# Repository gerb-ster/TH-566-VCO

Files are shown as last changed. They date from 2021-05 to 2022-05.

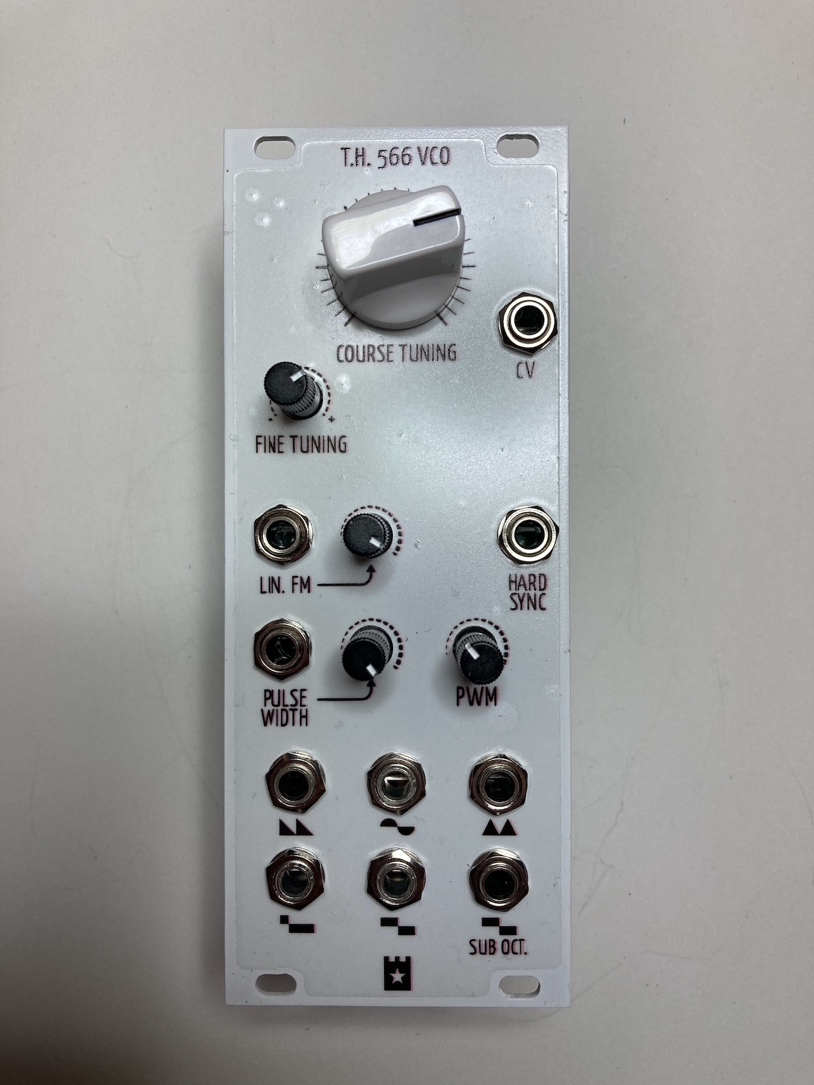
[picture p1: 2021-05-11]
images/IMG_3571.jpeg

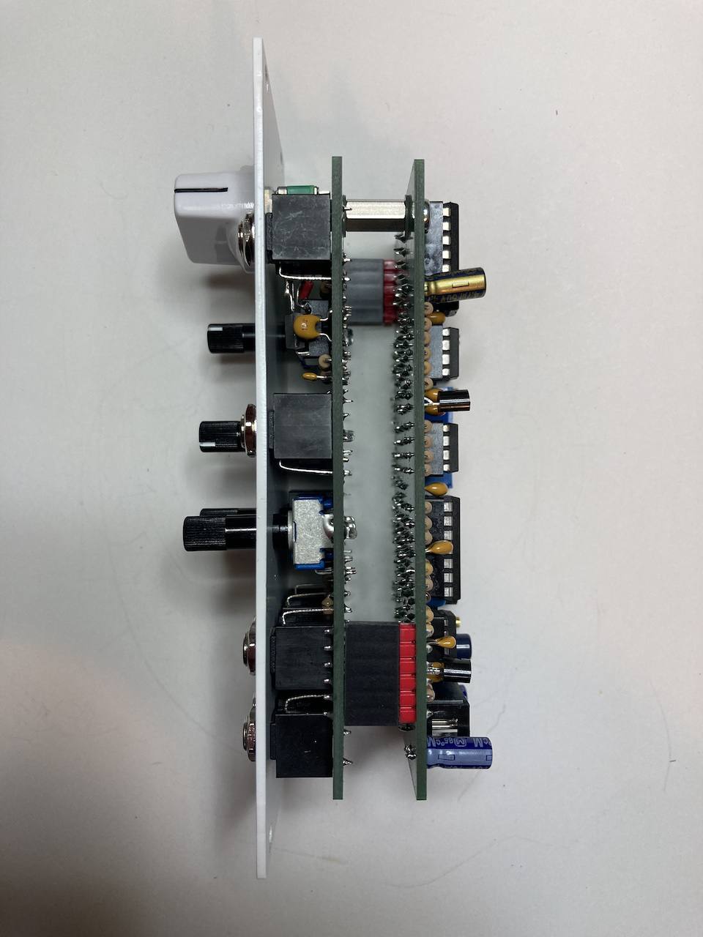
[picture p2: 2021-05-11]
images/IMG_3572.jpeg

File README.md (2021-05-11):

# Thomas Henry 566 VCO

Some years ago I bought a booklet called ‘making music with the 566’ by Thomas Henry. The first time I read it, I understood maybe 10 percent. Since then, every year or so, I’d read it again, and it started making more and more sense. And last year I decided it was time to try and make a PCB for it. So here it is. I’ve added a wave shaper to turn the triangle wave into a saw wave. I made some minor mistakes in the first PCB design, but these are fixed in the schematics below.

## Status: Finished

- done: first schematic & board design
- done: breadboard and test
- done: design frontpanel
- done: order PCB and build prototype

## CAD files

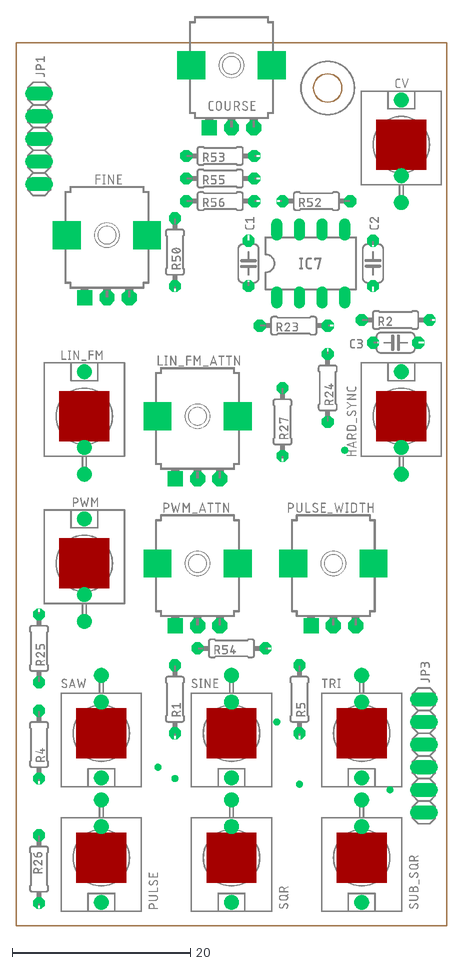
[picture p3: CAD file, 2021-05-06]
faceplates/th-566-vco-io.dxf
48.3 x 102.0

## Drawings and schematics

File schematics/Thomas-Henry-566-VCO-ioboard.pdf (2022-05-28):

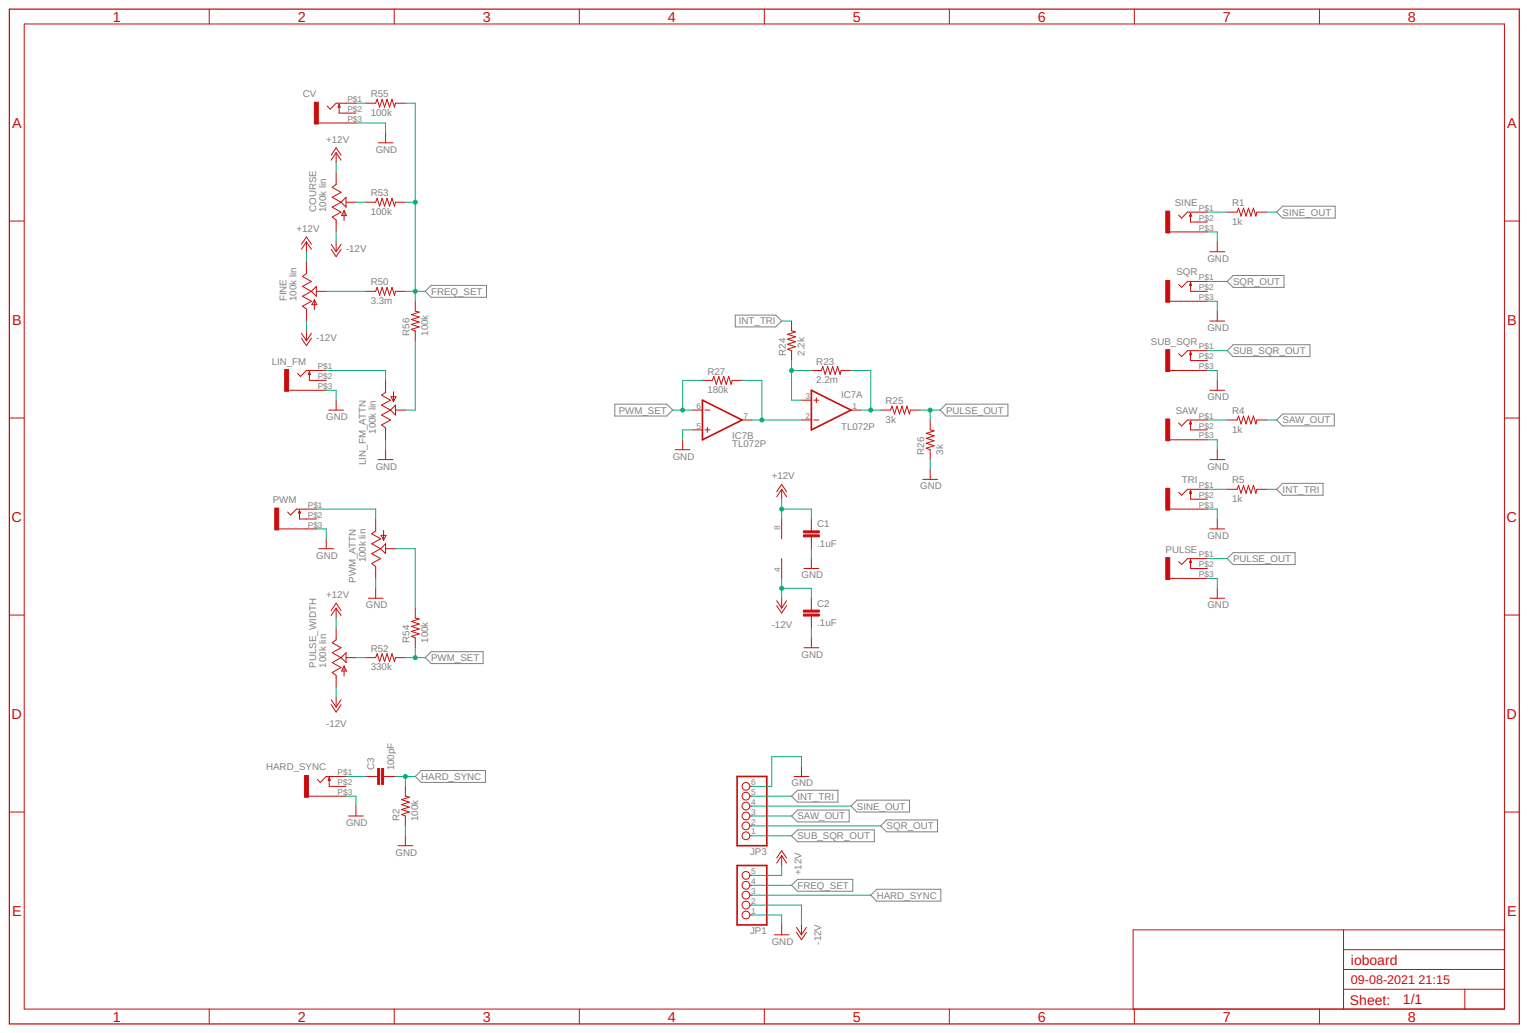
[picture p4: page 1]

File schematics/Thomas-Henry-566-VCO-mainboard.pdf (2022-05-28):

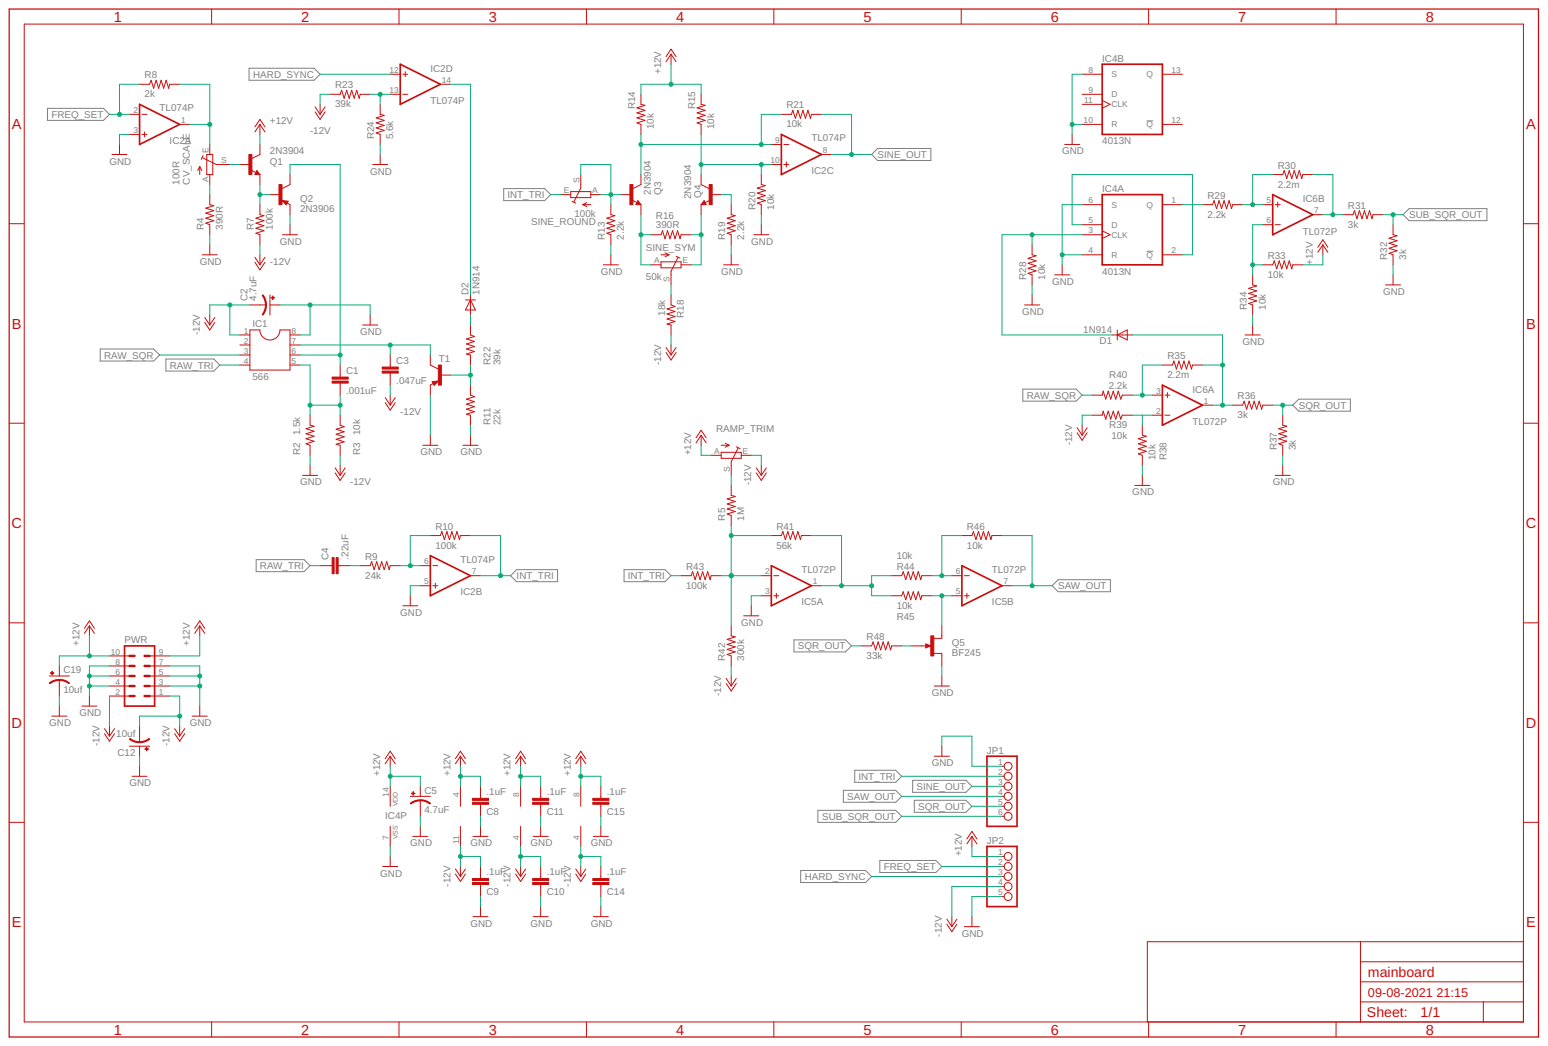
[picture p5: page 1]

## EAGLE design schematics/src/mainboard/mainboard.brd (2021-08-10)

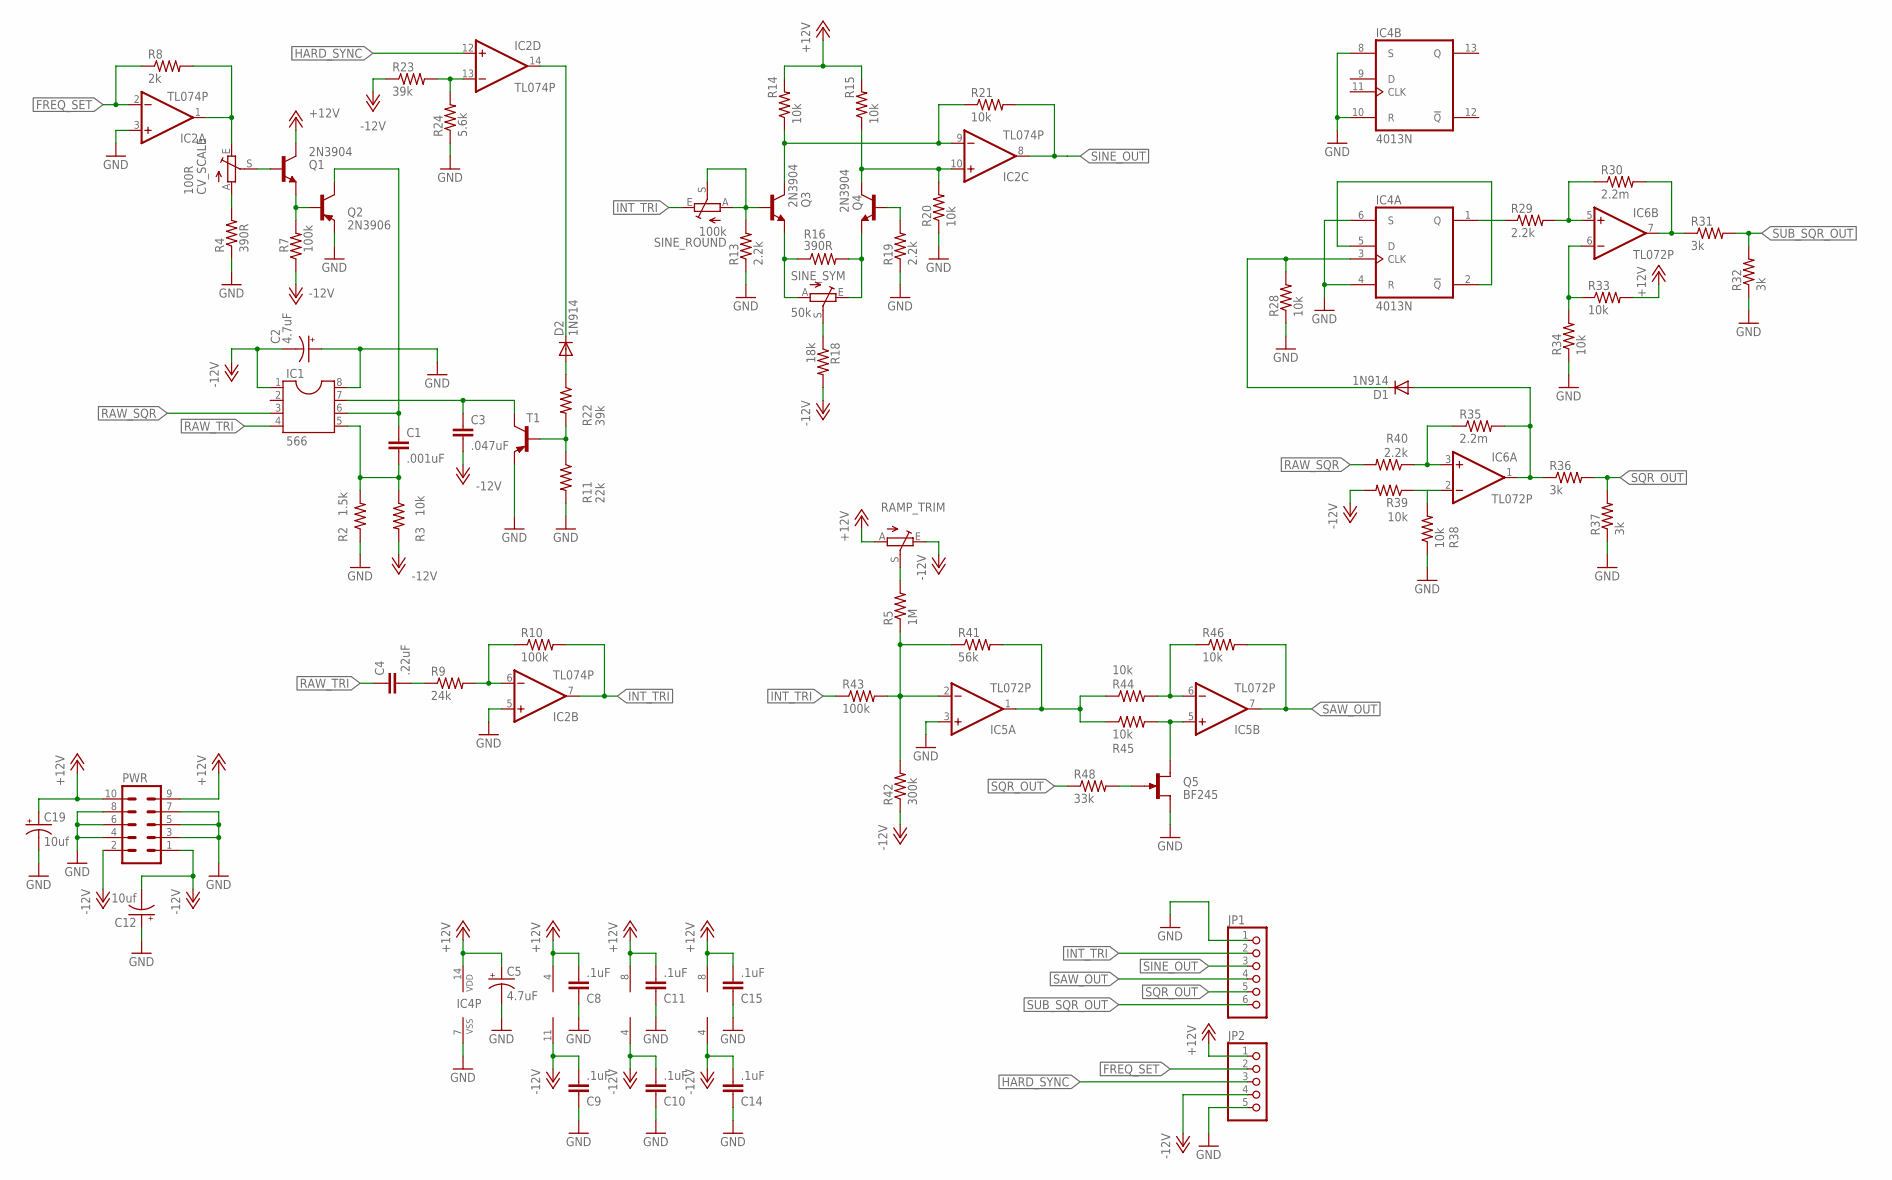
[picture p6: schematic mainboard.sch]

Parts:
C1: .001uF; C050-024X044
C2: 4.7uF; E2,5-6
C3: .047uF; C050-024X044
C4: .22uF; C050-024X044
C5: 4.7uF; E2,5-5
C8, C9, C10, C11, C14, C15: .1uF; C050-024X044
C12, C19: 10uf; E2,5-5
CV_SCALE: 100R; RJ9W
D1, D2: 1N914; DO35-7
IC1: 566; DIL08
IC2: TL074P; DIL14
IC4: 4013N; DIL14
IC5, IC6: TL072P; DIL08
JP1: PINHD-1X6; 1X06
JP2: PINHD-1X5; 1X05
PWR: ML10
Q1, Q3, Q4: 2N3904; TO92
Q2: 2N3906; TO92
Q5: BF245; SOT54C
R2: 1.5k; 0204/7
R3, R14, R15, R20, R21, R28, R33, R34, R38, R39, R44, R45, R46: 10k; 0204/7
R4, R16: 390R; 0204/7
R5: 1M; 0204/7
R7, R10, R43: 100k; 0204/7
R8: 2k; 0204/7
R9: 24k; 0204/7
R11: 22k; 0204/7
R13, R19, R29, R40: 2.2k; 0204/7
R18: 18k; 0204/7
R22, R23: 39k; 0204/7
R24: 5.6k; 0204/7
R30, R35: 2.2m; 0204/7
R31, R32, R36, R37: 3k; 0204/7
R41: 56k; 0204/7
R42: 300k; 0204/7
R48: 33k; 0204/7
RAMP_TRIM: TRIM_EU-RJ9W; RJ9W
SINE_ROUND: 100k; RJ9W
SINE_SYM: 50k; RJ9W
T1: 2N3906-PNP-TO92-EBC; TO92-EBC

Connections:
+12V: C5.+, C8.2, C11.2, C15.2, C19.+, IC2.4 (V+), IC4.14 (VDD), IC5.8 (V+), IC6.8 (V+), JP2.1, PWR.9, PWR.10, Q1.1 (C), R14.2, R15.2, R33.2, RAMP_TRIM.A
-12V: C2.-, C3.2, C9.2, C10.2, C12.-, C14.2, IC1.1, IC2.11 (V-), IC5.4 (V-), IC6.4 (V-), JP2.4, PWR.1, PWR.2, R3.2, R7.1, R18.2, R23.1, R39.2, R42.1, RAMP_TRIM.E
FREQ_SET: IC2.2 (-IN), JP2.2, R8.1
GND: C2.+, C5.-, C8.1, C9.1, C10.1, C11.1, C12.+, C14.1, C15.1, C19.-, IC1.8, IC2.3 (+IN), IC2.5 (+IN), IC4.4 (R), IC4.6 (S), IC4.7 (VSS), IC4.8 (S), IC4.10 (R), IC5.3 (+IN), JP1.1, JP2.5, PWR.3, PWR.4, PWR.5, PWR.6, PWR.7, PWR.8, Q2.3 (E), Q5.S, R2.1, R4.1, R11.2, R13.1, R19.1, R20.1, R24.1, R28.1, R32.1, R34.1, R37.1, R38.1, T1.E
HARD_SYNC: IC2.12 (+IN), JP2.3
INT_TRI: IC2.7 (OUT), JP1.2, R10.2, R43.1, SINE_ROUND.E
unnamed: C3.1, IC1.7, T1.C
unnamed: C1.2, IC1.5, R2.2, R3.1
unnamed: C1.1, IC1.6, Q2.1 (C)
unnamed: CV_SCALE.A, R4.2
unnamed: Q1.3 (E), Q2.2 (B), R7.2
unnamed: CV_SCALE.S, Q1.2 (B)
unnamed: CV_SCALE.E, IC2.1 (OUT), R8.2
unnamed: IC2.6 (-IN), R9.2, R10.1
unnamed: C4.2, R9.1
unnamed: IC5.6 (-IN), R44.2, R46.1
unnamed: R11.1, R22.2, T1.B
unnamed: IC4.1 (Q), R29.1
unnamed: IC2.10 (+IN), Q4.1 (C), R15.1, R20.2
unnamed: R18.1, SINE_SYM.S
unnamed: Q3.2 (B), R13.2, SINE_ROUND.A, SINE_ROUND.S
unnamed: IC2.9 (-IN), Q3.1 (C), R14.1, R21.1
unnamed: Q4.2 (B), R19.2
unnamed: Q3.3 (E), R16.1, SINE_SYM.A
unnamed: Q4.3 (E), R16.2, SINE_SYM.E
unnamed: D2.C, IC2.14 (OUT)
unnamed: IC6.5 (+IN), R29.2, R30.1
unnamed: D2.A, R22.1
unnamed: R5.2, RAMP_TRIM.S
unnamed: IC6.6 (-IN), R33.1, R34.2
unnamed: IC4.2 (!Q), IC4.5 (D)
unnamed: D1.C, IC4.3 (CLK), R28.2
unnamed: IC6.7 (OUT), R30.2, R31.1
unnamed: IC5.2 (-IN), R5.1, R41.1, R42.2, R43.2
unnamed: D1.A, IC6.1 (OUT), R35.2, R36.1
unnamed: IC2.13 (-IN), R23.2, R24.2
unnamed: IC6.2 (-IN), R38.2, R39.1
unnamed: IC6.3 (+IN), R35.1, R40.1
unnamed: IC5.1 (OUT), R41.2, R44.1, R45.1
unnamed: IC5.5 (+IN), Q5.D, R45.2
unnamed: Q5.G, R48.2
RAW_SQR: IC1.3, R40.2
RAW_TRI: C4.1, IC1.4
SAW_OUT: IC5.7 (OUT), JP1.4, R46.2
SINE_OUT: IC2.8 (OUT), JP1.3, R21.2
SQR_OUT: JP1.5, R36.2, R37.2, R48.1
SUB_SQR_OUT: JP1.6, R31.2, R32.2

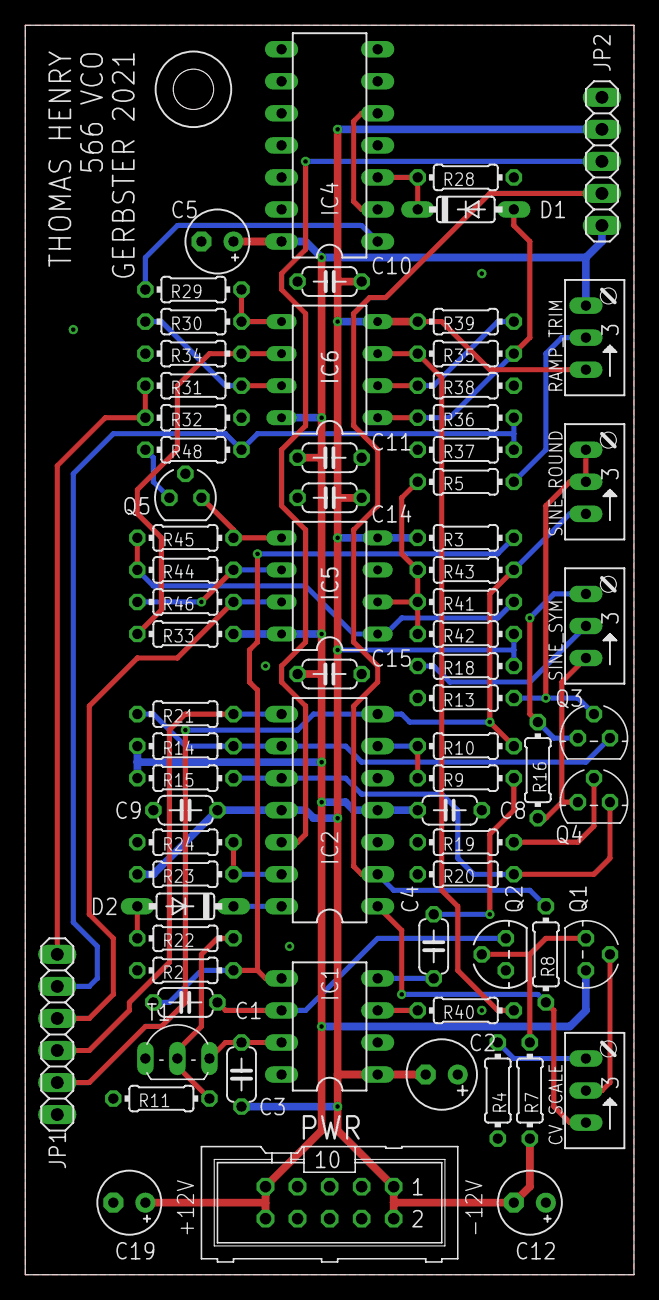
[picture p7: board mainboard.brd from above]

Board: 2 copper layers, 48.3 x 99.1 mm, 73 parts (0 on the bottom side), 47 nets.

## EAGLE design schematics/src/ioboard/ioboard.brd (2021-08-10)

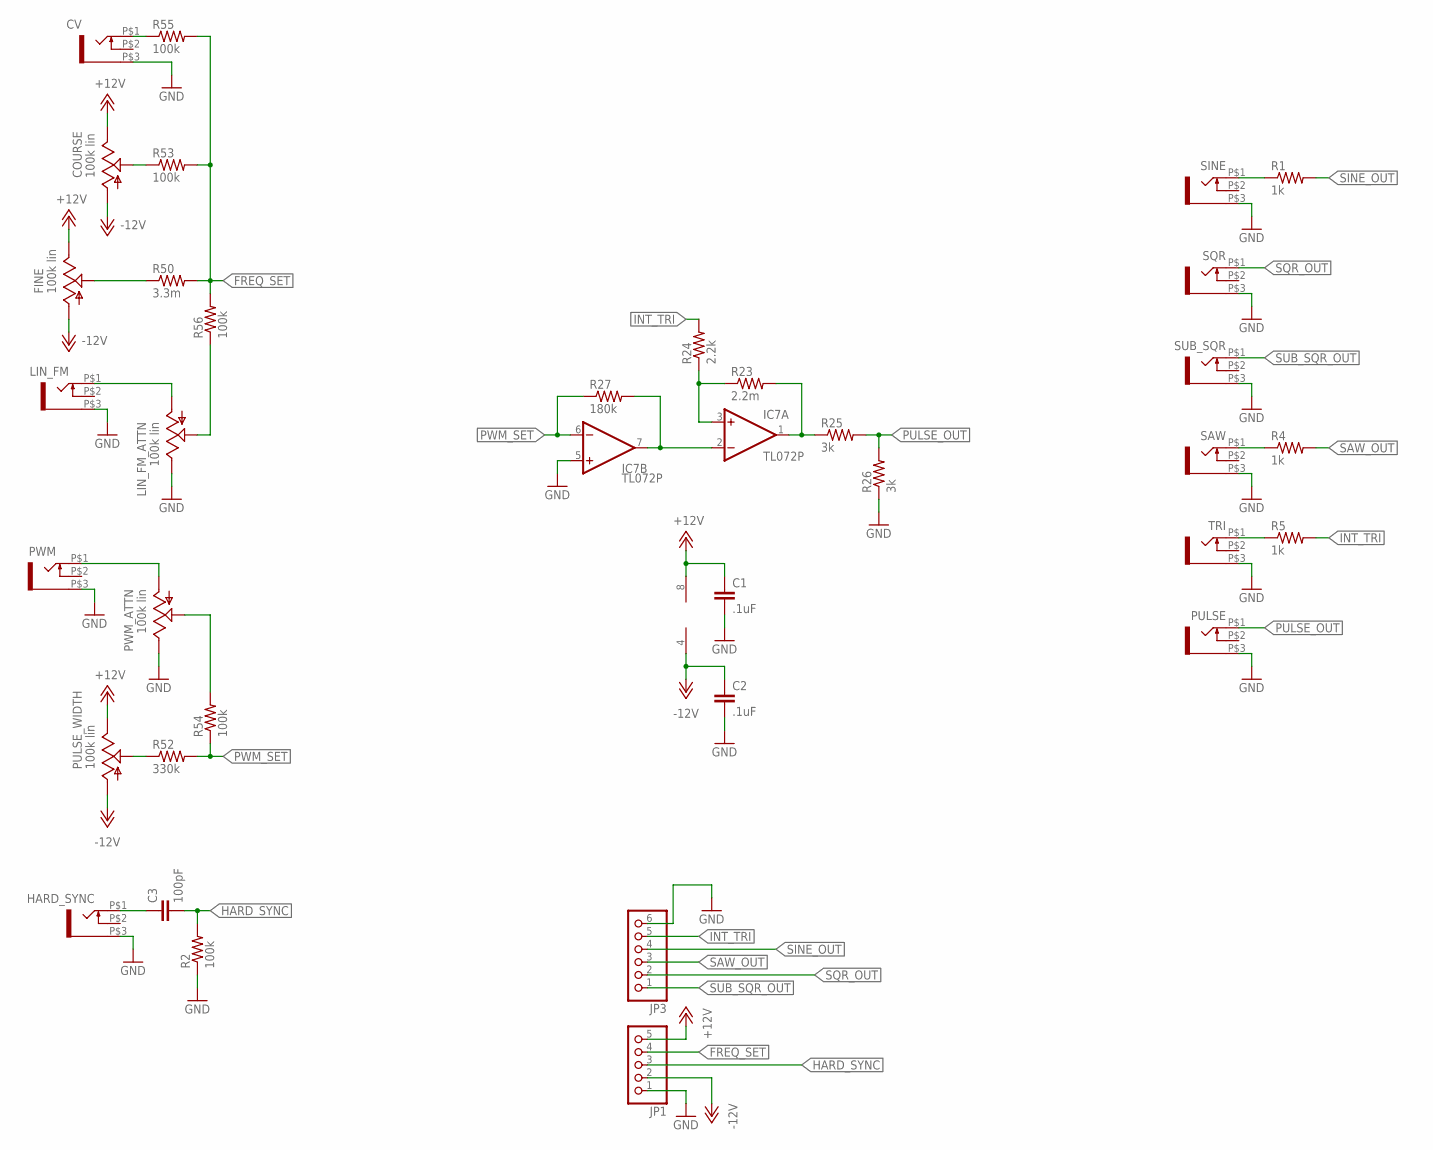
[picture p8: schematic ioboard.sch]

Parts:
C1, C2: .1uF; C050-024X044
C3: 100pF; C050-024X044
COURSE: 100k lin; EVUF
CV: WQP-PJ301M-12_JACK
FINE: 100k lin; EVUF
HARD_SYNC: WQP-PJ301M-12_JACK
IC7: TL072P; DIL08
JP1: PINHD-1X5; 1X05
JP3: PINHD-1X6; 1X06
LIN_FM: WQP-PJ301M-12_JACK
LIN_FM_ATTN: 100k lin; EVUF
PULSE: WQP-PJ301M-12_JACK
PULSE_WIDTH: 100k lin; EVUF
PWM: WQP-PJ301M-12_JACK
PWM_ATTN: 100k lin; EVUF
R1, R4, R5: 1k; 0204/7
R2, R53, R54, R55, R56: 100k; 0204/7
R23: 2.2m; 0204/7
R24: 2.2k; 0204/7
R25, R26: 3k; 0204/7
R27: 180k; 0204/7
R50: 3.3m; 0204/7
R52: 330k; 0204/7
SAW: WQP-PJ301M-12_JACK
SINE: WQP-PJ301M-12_JACK
SQR: WQP-PJ301M-12_JACK
SUB_SQR: WQP-PJ301M-12_JACK
TRI: WQP-PJ301M-12_JACK

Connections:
+12V: C1.1, COURSE.3 (E), FINE.3 (E), IC7.8 (V+), JP1.5, PULSE_WIDTH.3 (E)
-12V: C2.1, COURSE.1 (A), FINE.1 (A), IC7.4 (V-), JP1.2, PULSE_WIDTH.1 (A)
FREQ_SET: JP1.4, R50.2, R53.2, R55.2, R56.2
GND: C1.2, C2.2, CV.P$3 (1), HARD_SYNC.P$3 (1), IC7.5 (+IN), JP1.1, JP3.6, LIN_FM.P$3 (1), LIN_FM_ATTN.3 (E), PULSE.P$3 (1), PWM.P$3 (1), PWM_ATTN.3 (E), R2.1, R26.1, SAW.P$3 (1), SINE.P$3 (1), SQR.P$3 (1), SUB_SQR.P$3 (1), TRI.P$3 (1)
HARD_SYNC: C3.2, JP1.3, R2.2
INT_TRI: JP3.5, R5.2, R24.2
IO_PWM_IN: PWM_ATTN.2 (S), R54.2
unnamed: R1.1, SINE.P$1 (2)
unnamed: R5.1, TRI.P$1 (2)
unnamed: R4.1, SAW.P$1 (2)
unnamed: C3.1, HARD_SYNC.P$1 (2)
unnamed: IC7.1 (OUT), R23.2, R25.1
unnamed: IC7.2 (-IN), IC7.7 (OUT), R27.2
unnamed: IC7.3 (+IN), R23.1, R24.1
unnamed: PWM.P$1 (2), PWM_ATTN.1 (A)
unnamed: PULSE_WIDTH.2 (S), R52.1
unnamed: FINE.2 (S), R50.1
unnamed: COURSE.2 (S), R53.1
unnamed: CV.P$1 (2), R55.1
unnamed: LIN_FM.P$1 (2), LIN_FM_ATTN.1 (A)
unnamed: LIN_FM_ATTN.2 (S), R56.1
PULSE_OUT: PULSE.P$1 (2), R25.2, R26.2
PWM_SET: IC7.6 (-IN), R27.1, R52.2, R54.1
SAW_OUT: JP3.3, R4.2
SINE_OUT: JP3.4, R1.2
SQR_OUT: JP3.2, SQR.P$1 (2)
SUB_SQR_OUT: JP3.1, SUB_SQR.P$1 (2)

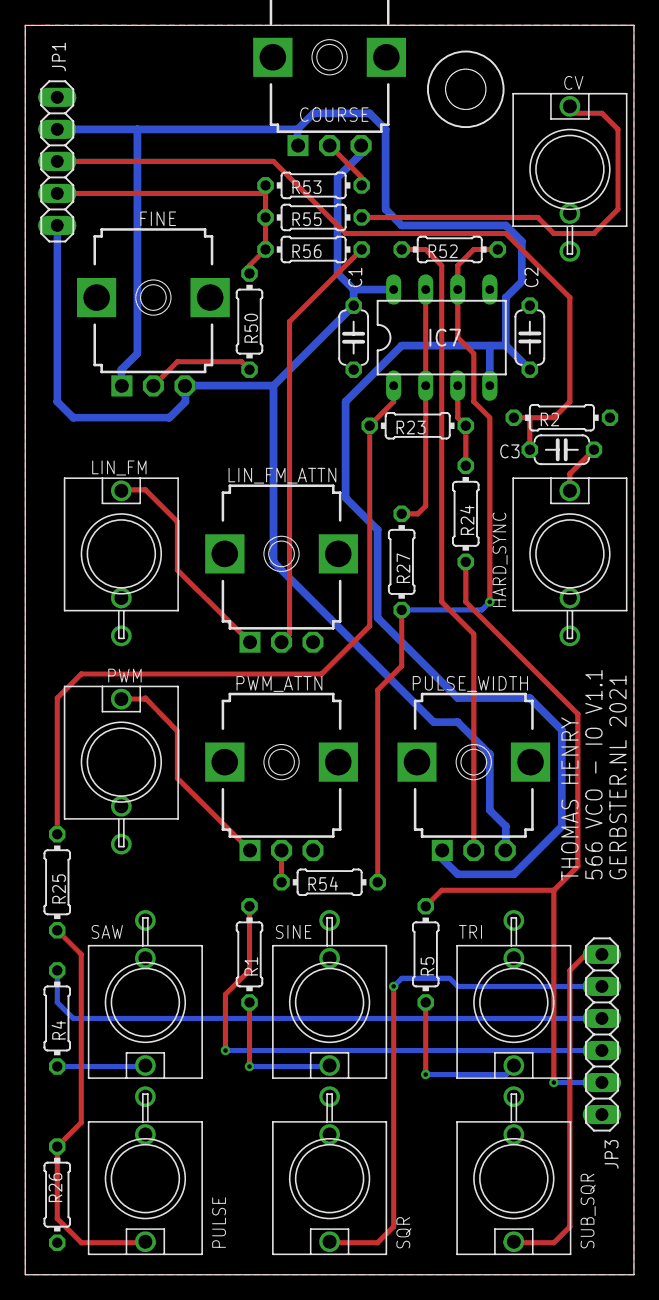
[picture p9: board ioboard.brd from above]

Board: 2 copper layers, 48.3 x 99.1 mm, 36 parts (0 on the bottom side), 27 nets.

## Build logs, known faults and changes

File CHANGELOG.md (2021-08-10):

# Changelog

All notable changes to this project will be documented in this file.

The format is based on [Keep a Changelog](https://keepachangelog.com/en/1.0.0/),
and this project adheres to [Semantic Versioning](https://semver.org/spec/v2.0.0.html).

## [1.1.0] - 2021-09-08

### Fixed

- Orientation of the Attenuators for Lin FM & PWM (thanks to Tymon Blaksell)
- Resistor values concerning the voltage dividers for the square, subsquare and pulse outputs (thanks to Tymon Blaksell)

## [1.0.1] - 2021-19-07

### Fixed

- Polarization of C2 cap on mainboard was wrong.

## [1.0.0] - 2021-01-05

### Added

- Inintial repo setup

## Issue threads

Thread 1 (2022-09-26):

one question of -12V and +12V

LegendaryTeacherLiu, 2022-09-26:
hi! thank you for watching.
there +12V and -12V port in the pcb of mainboard. The orientation of the socket installation on your blueprint and the finished photo is reversed。
I installed the socket according to the direction of the design drawing，It didn't work, and it burned. :( I look at your finished picture, the socket is installed in reverse.So what went wrong?should i follow your finished diagram to install the socket？

LegendaryTeacherLiu, 2022-09-26:
>
I've tried flipping the power supply and plugged it in and it still doesn't work, and my power box as a whole stopped working. I am confused, please advise.

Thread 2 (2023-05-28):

Ramp trim missing resistor type

saddeus, 2023-05-28:
In the BOM and on the Schematic, the ramp trim potentiometer on the mainboard  is missing its value.

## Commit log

2021-05-06 some files
    [th-566-vco-io.brd, th-566-vco-io.dxf, th-566-vco-io.sch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]
2021-05-07 Added files & structure
    [Thomas-Henry-566-VCO-ioboard.GBL, Thomas-Henry-566-VCO-ioboard.GBO, Thomas-Henry-566-VCO-ioboard.GBP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]
2021-06-15 Updated Schematics, Fixed Power Socket orientation
    [Thomas-Henry-566-VCO-ioboard.XLN, Thomas-Henry-566-VCO-mainboard.GBL, Thomas-Henry-566-VCO-mainboard.GBS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]
2021-07-19 Fixed minor issues, added documentation and updated some faceplates
    [mainboard.brd, mainboard.sch]
2021-08-06 Updated some schematics and docs
    [Thomas-Henry-566-VCO-ioboard.GBL, Thomas-Henry-566-VCO-ioboard.GBO, Thomas-Henry-566-VCO-ioboard.GBP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]
2021-08-10 Fixed some bugs and updated documentation
    [ioboard.brd, ioboard.sch, mainboard.brd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]
2022-04-20 Some updates & bugfixes
    [Thomas-Henry-566-VCO-ioboard.XLN, Thomas-Henry-566-VCO-mainboard.XLN, gerber_job.gbrjob]
2022-04-22 Fixed schematics & descriptions
    [Thomas-Henry-566-VCO-ioboard.XLN, Thomas-Henry-566-VCO-mainboard.XLN, gerber_job.gbrjob]
2022-05-17 Updated Firmware
    [Thomas-Henry-566-VCO-ioboard.XLN, Thomas-Henry-566-VCO-mainboard.XLN, gerber_job.gbrjob]
2022-05-18 Updated Faceplates
    [Thomas-Henry-566-VCO-ioboard.XLN, Thomas-Henry-566-VCO-mainboard.XLN, gerber_job.gbrjob]
2022-05-18 Fixed issues
    [Thomas-Henry-566-VCO-ioboard.XLN, Thomas-Henry-566-VCO-mainboard.XLN, gerber_job.gbrjob]
2022-05-21 Fixed schematics
    [Thomas-Henry-566-VCO-ioboard.XLN, Thomas-Henry-566-VCO-mainboard.XLN, gerber_job.gbrjob]
2022-05-28 General updates
    [Thomas-Henry-566-VCO-ioboard.GKO, Thomas-Henry-566-VCO-mainboard.GKO, copper_bottom.gbr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]
